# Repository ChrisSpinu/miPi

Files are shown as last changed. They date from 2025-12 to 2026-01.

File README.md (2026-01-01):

# miPi
Minimal MP3 player, based on the RP2354A, with an e-ink display and that can double as a media controller.


The MP3 player part will be handled directly by the RP2354A, outputing audio through two of its GPIO pins, while the radio receiver part of it will be handled by a RDA5807m module.

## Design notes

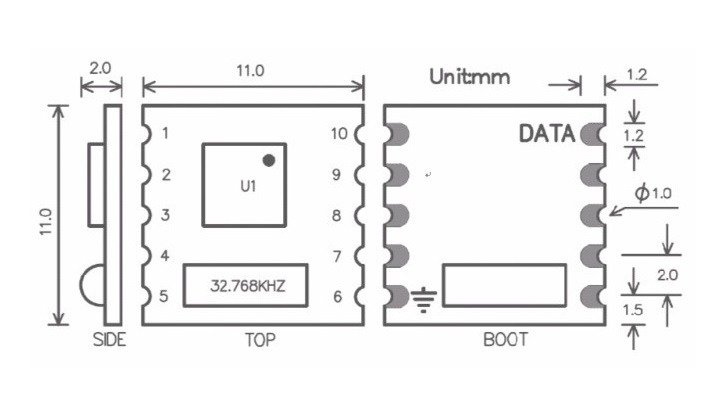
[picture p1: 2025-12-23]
docs/RDA5807M physical specs.jpg

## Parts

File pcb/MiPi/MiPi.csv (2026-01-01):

Reference | Value | DNP | Exclude from BOM | Exclude from Board | Footprint | LCSC
C1,C2,C3,C4,C5,C6,C7,C8,C9,C10,C11,C13 | 100n |  |  |  | Capacitor_SMD:C_0402_1005Metric | C1525
C12,C14,C15,C16,C27,C28 | 4.7u |  |  |  | Capacitor_SMD:C_0402_1005Metric | C23733
C17,C18 | 15p |  |  |  | Capacitor_SMD:C_0402_1005Metric | C86285
C19,C20,C21,C22,C23,C24,C25,C26,C29,C30,C31,C32 | 1u |  |  |  | Capacitor_SMD:C_0402_1005Metric | C29266
C33 | 22u |  |  |  | Capacitor_SMD:C_0402_1005Metric | C105226
C34 | 0.1u |  |  |  | Capacitor_SMD:C_0402_1005Metric | C1525
C35,C36,C37 | 100u |  |  |  | Capacitor_SMD:C_1206_3216Metric | C15008
C38,C39 | 10u |  |  |  | Capacitor_SMD:C_0402_1005Metric | C15525
D1,D2,D3 | MBR0530 |  |  |  | Diode_SMD:D_SOD-123 | C18863
J1 | Micro_SD_Card |  |  |  | Connector_Card:microSD_HC_Hirose_DM3D-SF | C719027
J2 | AudioJack3 |  |  |  | Connector_Audio:Jack_3.5mm_CUI_SJ-3523-SMT_Horizontal | C4991872
J3 | USB_C_Receptacle_USB2.0_14P |  |  |  | Connector_USB:USB_C_Receptacle_Amphenol_124019772112A | C5430474
L1 | 3.3u |  |  |  | RP2350_60QFN_minimal:L_pol_2016 | C42411119
L2 | 10u |  |  |  | Inductor_SMD:L_1206_3216Metric | C1051
Q1 | Si1308EDL |  |  |  | Package_TO_SOT_SMD:SOT-323_SC-70 | C4355112
R1 | 33 |  |  |  | Resistor_SMD:R_0402_1005Metric | C1091
R2,R3,R4 | 1k |  |  |  | Resistor_SMD:R_0402_1005Metric | C71623
R5,R6 | 27 |  |  |  | Resistor_SMD:R_0402_1005Metric | C1091
R7,R9,R10,R11,R12,R13,R14,R15,R16,R17,R18,R19,R20,R21,R26,R27 | 10k |  |  |  | Resistor_SMD:R_0402_1005Metric | C71617
R8 | 3 |  |  |  | Resistor_SMD:R_0402_1005Metric | C400520
R22,R23,R24,R25 | 3.9k |  |  |  | Resistor_SMD:R_0402_1005Metric | C278582
R28,R29 | 5k1 |  |  |  | Resistor_SMD:R_0402_1005Metric | C25941
SW1,SW2,SW4,SW5,SW6,SW7 | SW_Push |  |  |  | Button_Switch_SMD:SW_Push_1P1T_NO_CK_KMR2 | C269272
SW3 | RotaryEncoder_Switch_MP |  |  |  | Rotary_Encoder:RotaryEncoder_Alps_EC11E-Switch_Vertical_H20mm | C202365
U1 | RP2350_60QFN |  |  |  | RP2350_60QFN_minimal:RP2350-QFN-60-1EP_7x7_P0.4mm_EP3.4x3.4mm_ThermalVias | C41378174
U2 | ~ |  |  |  | USER Library:FPC_24_TOP_CONTACTS | C22751583
U3 | ~ |  | Excluded from BOM |  | USER Library:RDA5807M module
U4 | TS5A23159DGS |  |  |  | Package_SO:VSSOP-10_3x3mm_P0.5mm | C42751
U5 | TDA1308 |  |  |  | Package_SO:SOIC-8_3.9x4.9mm_P1.27mm | C38340
U6 | NCP1117-3.3_SOT223 |  |  |  | Package_TO_SOT_SMD:SOT-223-3_TabPin2 | C26537
Y1 | Crystal_GND24 |  |  |  | Crystal:Crystal_SMD_Abracon_ABM8G-4Pin_3.2x2.5mm | C20625731

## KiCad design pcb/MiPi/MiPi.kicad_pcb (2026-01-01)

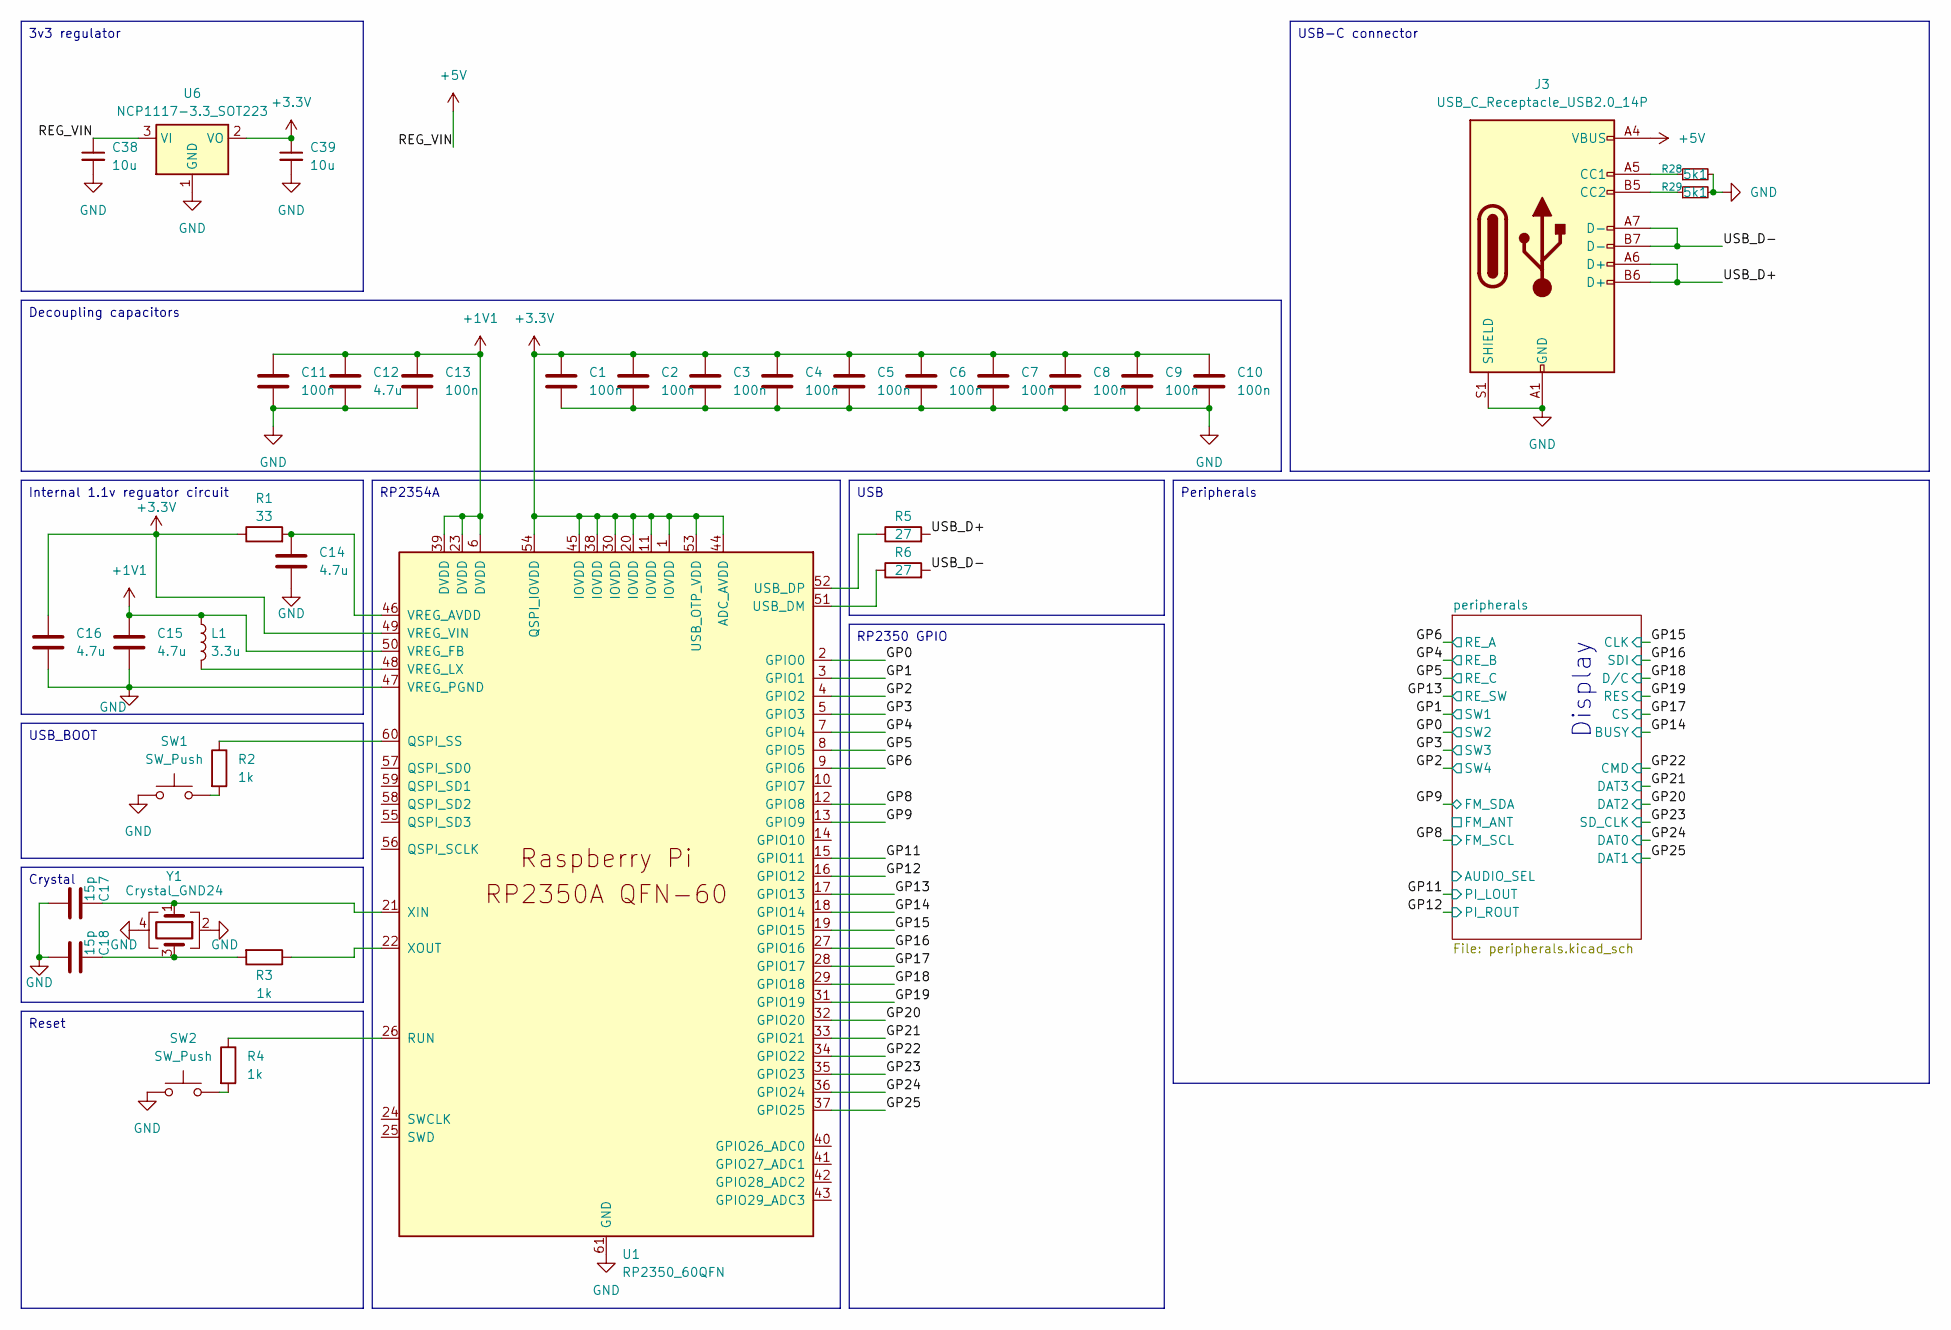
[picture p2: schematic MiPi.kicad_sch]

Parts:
C1, C2, C3, C4, C5, C6, C7, C8, C9, C10, C11, C13: 100n; C_0402_1005Metric; LCSC C1525
C12, C14, C15, C16: 4.7u; C_0402_1005Metric; LCSC C23733
C17, C18: 15p; C_0402_1005Metric; LCSC C86285
C38, C39: 10u; C_0402_1005Metric; LCSC C15525
J3: USB_C_Receptacle_USB2.0_14P; USB_C_Receptacle_Amphenol_124019772112A; LCSC C5430474
L1: 3.3u; L_pol_2016; LCSC C42411119
R1: 33; R_0402_1005Metric; LCSC C1091
R2, R3, R4: 1k; R_0402_1005Metric; LCSC C71623
R5, R6: 27; R_0402_1005Metric; LCSC C1091
R28, R29: 5k1; R_0402_1005Metric; LCSC C25941
SW1, SW2: SW_Push; SW_Push_1P1T_NO_CK_KMR2; LCSC C269272
U1: RP2350_60QFN; RP2350-QFN-60-1EP_7x7_P0.4mm_EP3.4x3.4mm_ThermalVias; LCSC C41378174
U6: NCP1117-3.3_SOT223; SOT-223-3_TabPin2; LCSC C26537
Y1: Crystal_GND24; Crystal_SMD_Abracon_ABM8G-4Pin_3.2x2.5mm; LCSC C20625731

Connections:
+1V1: C11.1, C12.1, C13.1, C15.1, L1.1, U1.6 (DVDD), U1.23 (DVDD), U1.39 (DVDD), U1.50 (VREG_FB)
+3.3V: C1.1, C2.1, C3.1, C4.1, C5.1, C6.1, C7.1, C8.1, C9.1, C10.1, C16.1, C39.1, R1.1, U1.1 (IOVDD), U1.11 (IOVDD), U1.20 (IOVDD), U1.30 (IOVDD), U1.38 (IOVDD), U1.44 (ADC_AVDD), U1.45 (IOVDD), U1.49 (VREG_VIN), U1.53 (USB_OTP_VDD), U1.54 (QSPI_IOVDD), U6.2 (VO); also elsewhere on the board
+5V: C38.1, J3.A4 (VBUS), J3.A9 (VBUS), J3.B4 (VBUS), J3.B9 (VBUS), U6.3 (VI)
/GP0: U1.2 (GPIO0); also elsewhere on the board
/GP1: U1.3 (GPIO1); also elsewhere on the board
/GP2: U1.4 (GPIO2); also elsewhere on the board
/GP3: U1.5 (GPIO3); also elsewhere on the board
/GP4: U1.7 (GPIO4); also elsewhere on the board
/GP5: U1.8 (GPIO5); also elsewhere on the board
/GP6: U1.9 (GPIO6); also elsewhere on the board
/GP8: U1.12 (GPIO8); also elsewhere on the board
/GP9: U1.13 (GPIO9); also elsewhere on the board
/GP11: U1.15 (GPIO11); also elsewhere on the board
/GP12: U1.16 (GPIO12); also elsewhere on the board
/GP13: U1.17 (GPIO13); also elsewhere on the board
/GP14: U1.18 (GPIO14); also elsewhere on the board
/GP15: U1.19 (GPIO15); also elsewhere on the board
/GP16: U1.27 (GPIO16); also elsewhere on the board
/GP17: U1.28 (GPIO17); also elsewhere on the board
/GP18: U1.29 (GPIO18); also elsewhere on the board
/GP19: U1.31 (GPIO19); also elsewhere on the board
/GP20: U1.32 (GPIO20); also elsewhere on the board
/GP21: U1.33 (GPIO21); also elsewhere on the board
/GP22: U1.34 (GPIO22); also elsewhere on the board
/GP23: U1.35 (GPIO23); also elsewhere on the board
/GP24: U1.36 (GPIO24); also elsewhere on the board
/GP25: U1.37 (GPIO25); also elsewhere on the board
/USB_D+: J3.A6 (D+), J3.B6 (D+), R5.2
/USB_D-: J3.A7 (D-), J3.B7 (D-), R6.2
GND: C1.2, C2.2, C3.2, C4.2, C5.2, C6.2, C7.2, C8.2, C9.2, C10.2, C11.2, C12.2, C13.2, C14.2, C15.2, C16.2, C17.2, C18.2, C38.2, C39.2, J3.A1 (GND), J3.A12 (GND), J3.B1 (GND), J3.B12 (GND), J3.S1 (SHIELD), R28.2, R29.2, SW1.1, SW2.1, U1.47 (VREG_PGND), U1.61 (GND), U6.1 (GND), Y1.2, Y1.4; also elsewhere on the board
unnamed: C18.1, R3.2, Y1.3
unnamed: J3.A5 (CC1), R28.1
unnamed: J3.B5 (CC2), R29.1
unnamed: R2.2, SW1.2
unnamed: R4.2, SW2.2
unnamed: R2.1, U1.60 (QSPI_SS)
unnamed: R4.1, U1.26 (RUN)
unnamed: R6.1, U1.51 (USB_DM)
unnamed: R5.1, U1.52 (USB_DP)
unnamed: C14.1, R1.2, U1.46 (VREG_AVDD)
unnamed: L1.2, U1.48 (VREG_LX)
unnamed: C17.1, U1.21 (XIN), Y1.1
unnamed: R3.1, U1.22 (XOUT)

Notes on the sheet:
Display
USB-C connector
USB
Decoupling capacitors
RP2350 GPIO
USB_BOOT
Crystal
RP2354A
Peripherals
3v3 regulator
Internal 1.1v reguator circuit
Reset

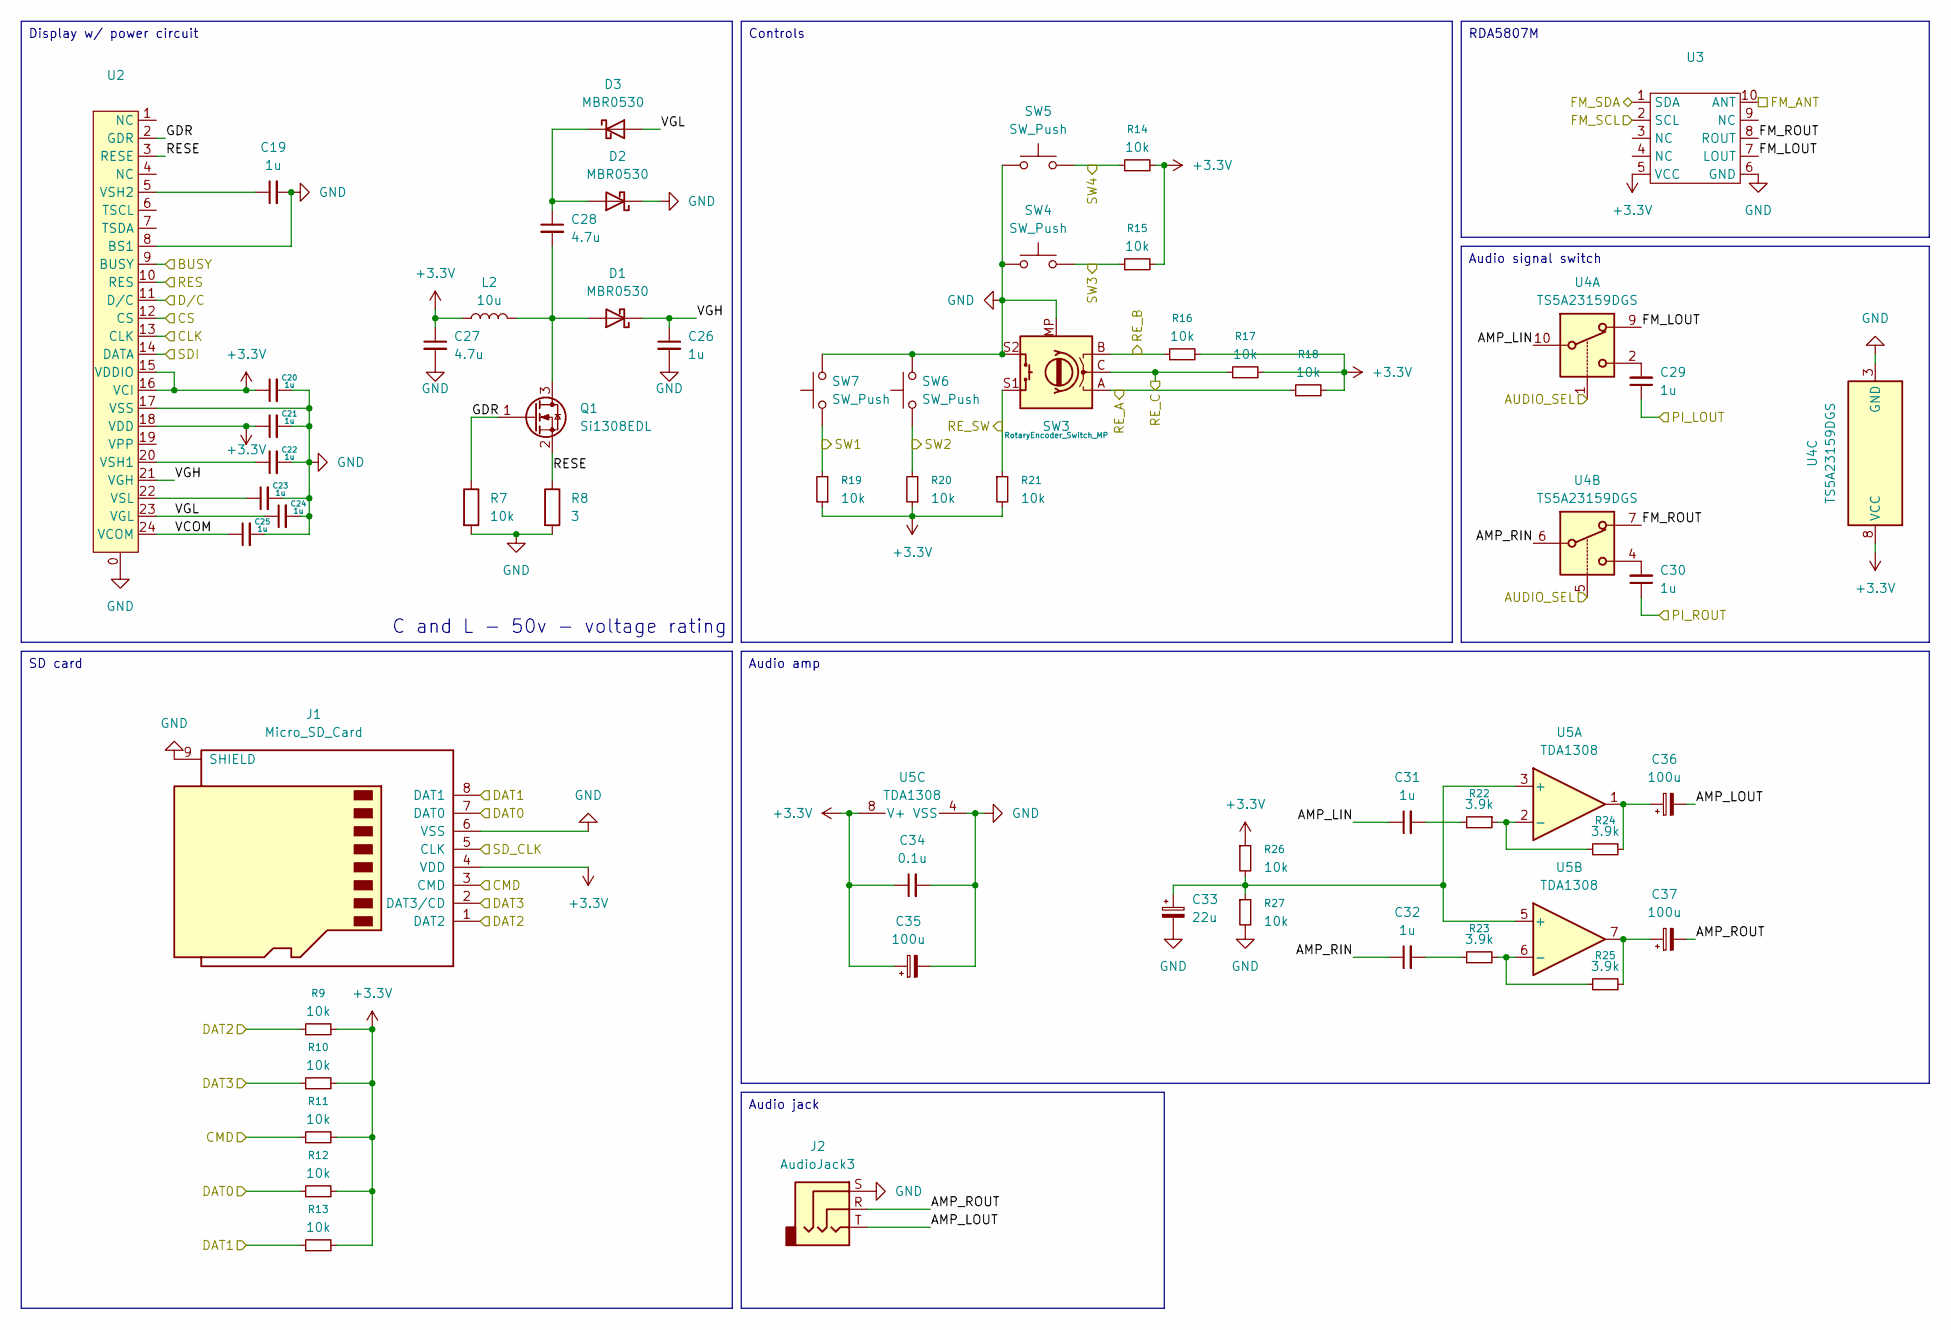
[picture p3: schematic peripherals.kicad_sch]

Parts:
C19, C20, C21, C22, C23, C24, C25, C26, C29, C30, C31, C32: 1u; C_0402_1005Metric; LCSC C29266
C27, C28: 4.7u; C_0402_1005Metric; LCSC C23733
C33: 22u; C_0402_1005Metric; LCSC C105226
C34: 0.1u; C_0402_1005Metric; LCSC C1525
C35, C36, C37: 100u; C_1206_3216Metric; LCSC C15008
D1, D2, D3: MBR0530; D_SOD-123; LCSC C18863
J1: Micro_SD_Card; microSD_HC_Hirose_DM3D-SF; LCSC C719027
J2: AudioJack3; Jack_3.5mm_CUI_SJ-3523-SMT_Horizontal; LCSC C4991872
L2: 10u; L_1206_3216Metric; LCSC C1051
Q1: Si1308EDL; SOT-323_SC-70; LCSC C4355112
R7, R9, R10, R11, R12, R13, R14, R15, R16, R17, R18, R19, R20, R21, R26, R27: 10k; R_0402_1005Metric; LCSC C71617
R8: 3; R_0402_1005Metric; LCSC C400520
R22, R23, R24, R25: 3.9k; R_0402_1005Metric; LCSC C278582
SW3: RotaryEncoder_Switch_MP; RotaryEncoder_Alps_EC11E-Switch_Vertical_H20mm; LCSC C202365
SW4, SW5, SW6, SW7: SW_Push; SW_Push_1P1T_NO_CK_KMR2; LCSC C269272
U2: FPC_24_TOP_CONTACTS; LCSC C22751583
U3: RDA5807M module
U4: TS5A23159DGS; VSSOP-10_3x3mm_P0.5mm; LCSC C42751
U5: TDA1308; SOIC-8_3.9x4.9mm_P1.27mm; LCSC C38340

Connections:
+3.3V: C20.1, C21.1, C27.1, C34.1, C35.1, J1.4 (VDD), L2.1, R9.2, R10.2, R11.2, R12.2, R13.2, R14.2, R15.2, R16.2, R17.2, R18.2, R19.1, R20.1, R21.2, R26.1, U2.15 (VDDIO), U2.16 (VCI), U2.18 (VDD), U3.5 (VCC), U4.8 (VCC), U5.8 (V+); also elsewhere on the board
/GP0: R20.2, SW6.1; also elsewhere on the board
/GP1: R19.2, SW7.1; also elsewhere on the board
/GP2: R14.1, SW5.2; also elsewhere on the board
/GP3: R15.1, SW4.2; also elsewhere on the board
/GP4: R16.1, SW3.B; also elsewhere on the board
/GP5: R17.1, SW3.C; also elsewhere on the board
/GP6: R18.1, SW3.A; also elsewhere on the board
/GP8: U3.2 (SCL); also elsewhere on the board
/GP9: U3.1 (SDA); also elsewhere on the board
/GP11: C29.1; also elsewhere on the board
/GP12: C30.1; also elsewhere on the board
/GP13: R21.1, SW3.S1; also elsewhere on the board
/GP14: U2.9 (BUSY); also elsewhere on the board
/GP15: U2.13 (CLK); also elsewhere on the board
/GP16: U2.14 (DATA); also elsewhere on the board
/GP17: U2.12 (CS); also elsewhere on the board
/GP18: U2.11 (D/C); also elsewhere on the board
/GP19: U2.10 (RES); also elsewhere on the board
/GP20: J1.1 (DAT2), R9.1; also elsewhere on the board
/GP21: J1.2 (DAT3/CD), R10.1; also elsewhere on the board
/GP22: J1.3 (CMD), R11.1; also elsewhere on the board
/GP23: J1.5 (CLK); also elsewhere on the board
/GP24: J1.7 (DAT0), R12.1; also elsewhere on the board
/GP25: J1.8 (DAT1), R13.1; also elsewhere on the board
/peripherals/AMP_LIN: C31.1, U4.10
/peripherals/AMP_LOUT: C36.2, J2.T
/peripherals/AMP_RIN: C32.1, U4.6
/peripherals/AMP_ROUT: C37.2, J2.R
/peripherals/AUDIO_SEL: U4.1, U4.5
/peripherals/FM_ANT: U3.10 (ANT)
/peripherals/FM_LOUT: U3.7 (LOUT), U4.9
/peripherals/FM_ROUT: U3.8 (ROUT), U4.7
/peripherals/GDR: Q1.1 (G), R7.1, U2.2 (GDR)
/peripherals/RESE: Q1.2 (S), R8.1, U2.3 (RESE)
/peripherals/VCOM: C25.1, U2.24 (VCOM)
/peripherals/VGH: C26.1, D1.1 (K), U2.21 (VGH)
/peripherals/VGL: C24.1, D3.2 (A), U2.23 (VGL)
GND: C19.2, C20.2, C21.2, C22.2, C23.2, C24.2, C25.2, C26.2, C27.2, C33.2, C34.2, C35.2, D2.1 (K), J1.6 (VSS), J1.9 (SHIELD), J2.S, R7.2, R8.2, R27.2, SW3.MP, SW3.S2, SW4.1, SW5.1, SW6.2, SW7.2, U2.0, U2.8 (BS1), U2.17 (VSS), U3.6 (GND), U4.3 (GND), U5.4 (VSS); also elsewhere on the board
unnamed: C29.2, U4.2
unnamed: C30.2, U4.4
unnamed: C31.2, R22.2
unnamed: C32.2, R23.1
unnamed: C36.1, R24.2, U5.1
unnamed: C37.1, R25.2, U5.7
unnamed: C28.2, D1.2 (A), L2.2, Q1.3 (D)
unnamed: C28.1, D2.2 (A), D3.1 (K)
unnamed: C22.1, U2.20 (VSH1)
unnamed: C19.1, U2.5 (VSH2)
unnamed: C23.1, U2.22 (VSL)
unnamed: C33.1, R26.2, R27.1, U5.3 (+), U5.5 (+)
unnamed: R22.1, R24.1, U5.2 (-)
unnamed: R23.2, R25.1, U5.6 (-)

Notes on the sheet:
C and L - 50v - voltage rating
Audio signal switch
Controls
RDA5807M
Audio amp
SD card
Audio jack
Display w/ power circuit

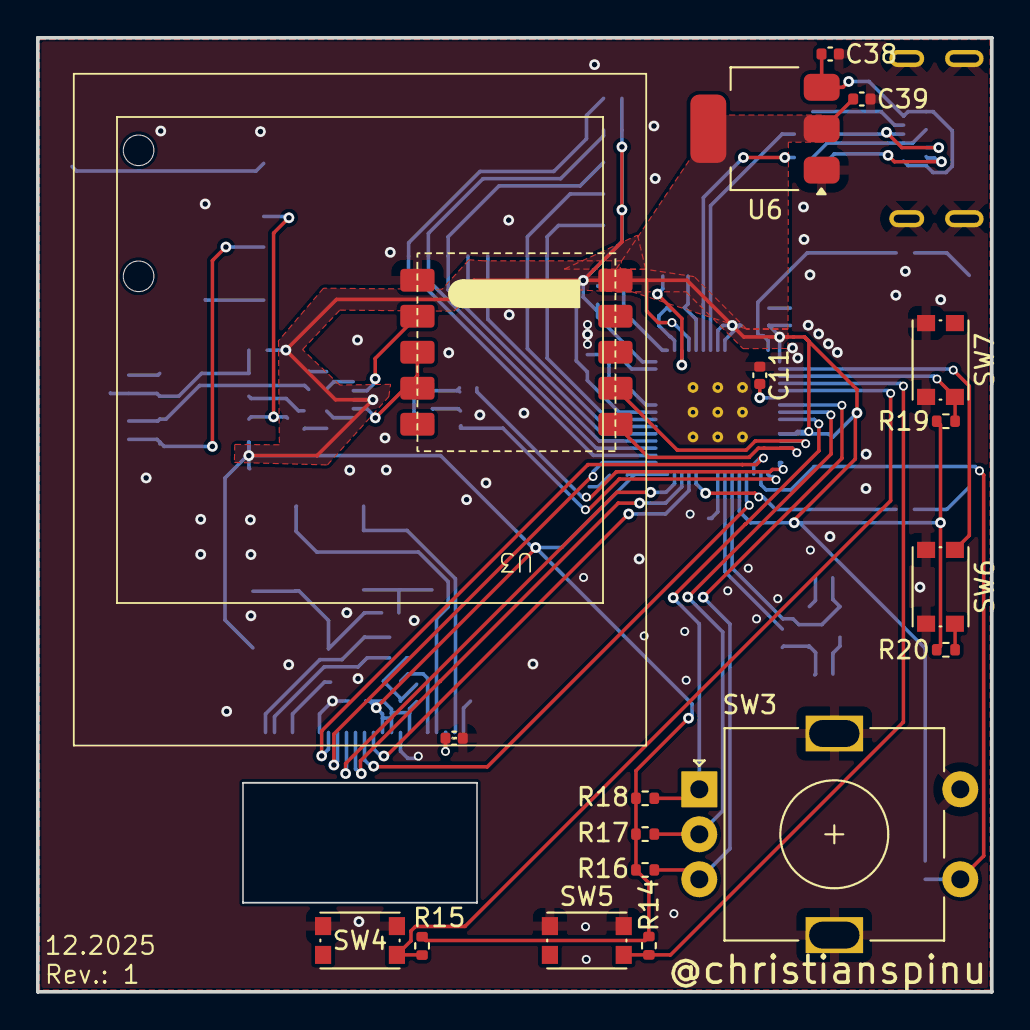
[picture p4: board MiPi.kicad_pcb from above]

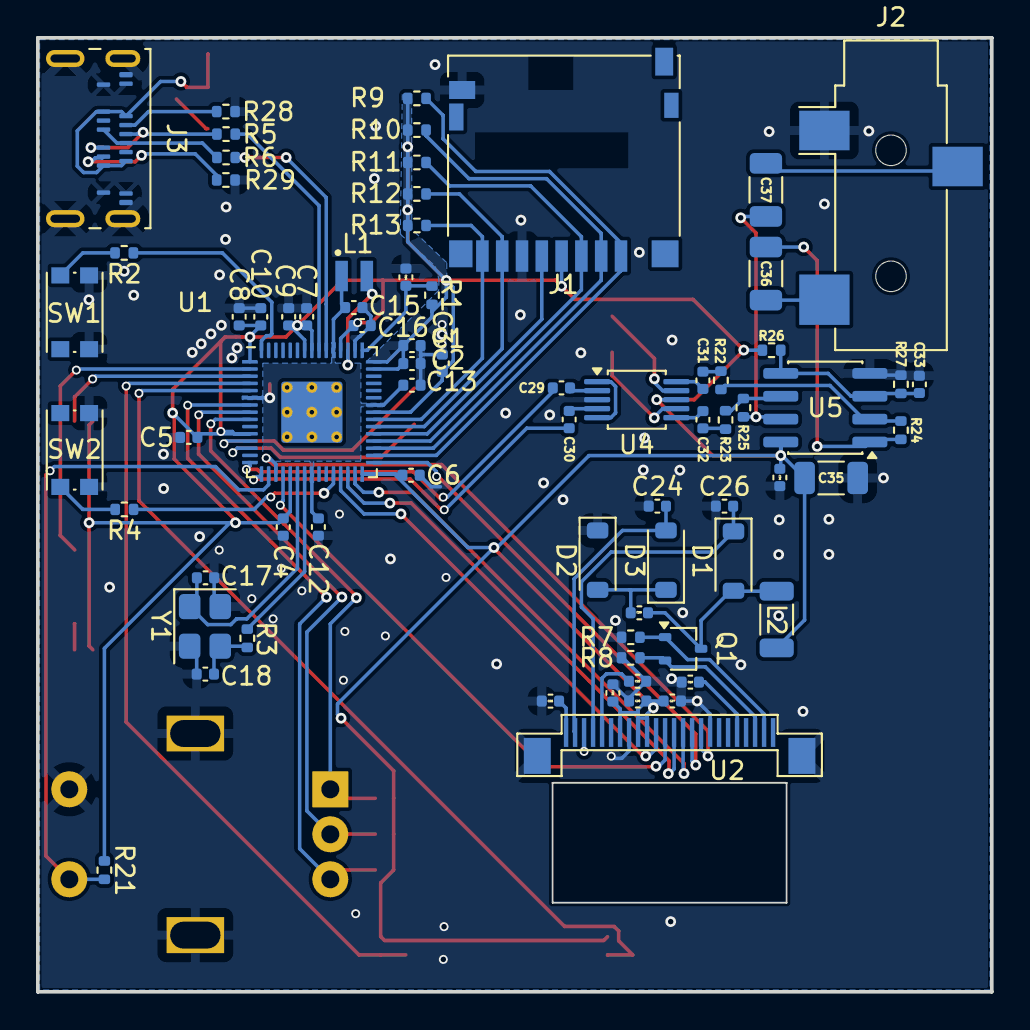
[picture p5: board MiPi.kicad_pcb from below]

Board: 2 copper layers, 53.0 x 53.0 mm, 91 parts (73 on the bottom side), 69 nets.

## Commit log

2025-12-17 Started the schematic design
    Almost done with the power circuitry, following the Raspberry Pi Foundation's RP2350 minimal design document.
    [MiPi.kicad_sch]
2025-12-17 MCU chip design done
    I finished doing the RP2354A schematic design. To Do: 3v3 regulator, USB connector, check 1v1 circuitry design.
    [MiPi.kicad_sch]
2025-12-21 Update MiPi.kicad_sch
    1v1 regulator circuitry seems all right, needed to specify a capacitor's value.
    [MiPi.kicad_sch]
2025-12-21 Display driving circuit done
    [MiPi.kicad_sch, peripherals.kicad_sch]
2025-12-23 Did RDA5807M, controls and SD circuit schematic
    [MiPi.kicad_sch, peripherals.kicad_sch]
2025-12-24 Peripherals sheet basically finished; Needs a check.
    Added an analog switch for selecting between the radio audio and the RP2350's audio; A headphone audio amp and an audio jack
    [MiPi.kicad_sch, peripherals.kicad_sch]
2025-12-24 Added USB-C connector
    Remaining To Do-s: connect the peripherals to GPIO, figure out if and how to implement a rechargeable LiPo battery, 3v3 regulator, and check the all the circuit again!
    [MiPi.kicad_sch, peripherals.kicad_sch]
2025-12-25 Started routing the PCB
    Done with the RP2350's decoupling caps, buttons and USB-C connector; Done with the display's driving circuit.
    [MiPi.kicad_pcb, MiPi.kicad_sch, peripherals.kicad_sch]
2025-12-27 Routed the analog switch and audio amp and audio jack
    [MiPi.kicad_pcb, MiPi.kicad_sch]
2025-12-28 Done the PCB layout
    Remaining ground planes and power routing
    [MiPi.kicad_pcb, MiPi.kicad_sch]
2025-12-30 Finished power routing
2025-12-30 Made a cut in the PCB
    Made a cut in the PCB where the display's FPC bends around to the back where the connector sits
    [MiPi.kicad_pcb]
2026-01-01 Made the Gerbers, BOM, and CDL for the first version of miPi
    [MiPi-B_Cu.gbr, MiPi-B_Mask.gbr, MiPi-B_Paste.gbr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]
